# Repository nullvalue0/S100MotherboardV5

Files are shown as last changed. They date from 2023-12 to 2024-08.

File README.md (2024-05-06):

# S-100 Motherboard V5
## 9-Slot Active Termination S-100 Motherboard with Integrated Power Supply

This motherboard is an update to the publically available motherboard designs at http://www.s100computers.com/My%20System%20Pages/S100%20Motherboard/S100%20Motherboard.htm.

I really enjoy working on vintage S-100 systems, however they are very heavy/bulky systems and do not lend themselves well to testing small systems or performing bench diagnostics. I would really like to have a small motherboard that has all of the power requirements already taken care of. The previous motherboard design relies on an external power supply to provide the "odd" voltages (by today's standards): +8V, +16V and -16V. Generating these voltages usually means cobbling together a few Meanwell (or similar) power supplies. This version uses 3 different switched mode power regulator modules to get "close enough" to the S-100 voltages. I've gone with a 7.5V and 15V module from Pololu, and a negative module providing -15V made by TI. Each S-100 card has their own voltage regulator(s) which convert the motherboard voltages to +5V, often times ±12V. Due to this, being off 0.5-1V in our motherboard shouldn't cause any issues. In fact the slightly lower voltages should help the boards run slightly cooler. The motherboard receives base power from an external 24V laptop power supply, through a barrel jack connector.

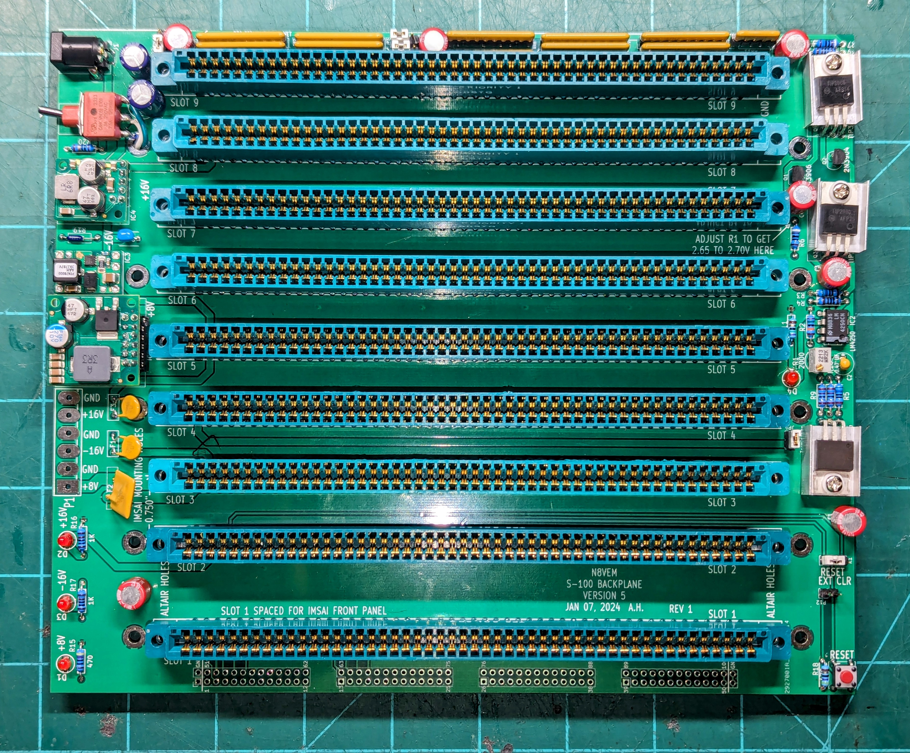
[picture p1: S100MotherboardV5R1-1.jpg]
S-100 Motherboard V5


One limitation of using these switching regulators is that current will be limited. It should be ok to power 3 or 4 standard S-100 cards. Any more than that and you'll start to push the limits. This motherboard is not intended to run large/power-hungry systems. Please be considerate of the amperage requirements of the cards you are using. I'd suggest using SIP socket strips for mounting the power supplies. That way if you need to provide external power for one of the voltages, say the +8V line, you could easily remove the 7.5V module and provide power from a bench supply.

If you do choose to populate the active termination components (which is optional, BTW) then I'd also recommend using SIP socket strips to populate the resistor packs. This way if you have a board set you want to use without termination, you can easily disable this feature by removing the resistors and the JP4 jumper.

I have a project set up through Mouser which has most of the parts required to build this motherboard: https://www.mouser.com/ProjectManager/ProjectDetail.aspx?AccessID=847fe5a657

There are a few parts not included in the Mouser project above:
- LM4250CN - this Op Amp IC is discontinued but can still be found on eBay
- 24V power supply (5.5mm x 2.1mm barrel connector). While I targeted a 24V input, any voltage between 15V-29V should work. I ordered the 7A version of this one and it's working great: https://www.ebay.com/itm/393979601717?var=662535600213
- 7.5V, 5A Step-Down Voltage Regulator D36V50F7 https://www.pololu.com/product/4093
- 15V, 2.7A Step-Down Voltage Regulator D30V30F15 https://www.pololu.com/product/4897
- S-100 slot connectors - sorry you're on your own for these - they can be expensive ($12-17 ea), so populate as few or as many as you'll actually need.
- 3 standard LEDs (I had plenty in my parts bin)
- Jumpers (will need up to 8)
- 2.54mm pitch pin headers for jumpers
- 3 heatsinks for TO-220 parts (7805 and TIP29/30)

This revision has kept all the great features of the V3 and V4 motherboards including:
- Active Termination to accomodate fasters speeds on the bus
- 9 S-100 slots
- Expansion/Logic Analyzer hookups
- Fused external power supply connector
- Mounting holes for Altair/IMSAI cases
- Reset switch

And I've done the following:
- Updated schematic/pcb to Kicad 7.0 and included all necessary libraries
- Synced up all parts between schematic & PCB to allow execution of DRC
- Increased edge connector pin hole sizes to 0.042"
- Changed fuses to resettable fuses
- Added 3 On-board power supplies
- Added Power On/Off toggle switch
- Added 3-way jumpers for 3 legacy pins to choose if you want to ground those pins, leave them unterminated, or active terminated
- Added jumper to enable/disable active termination power and indicator LED

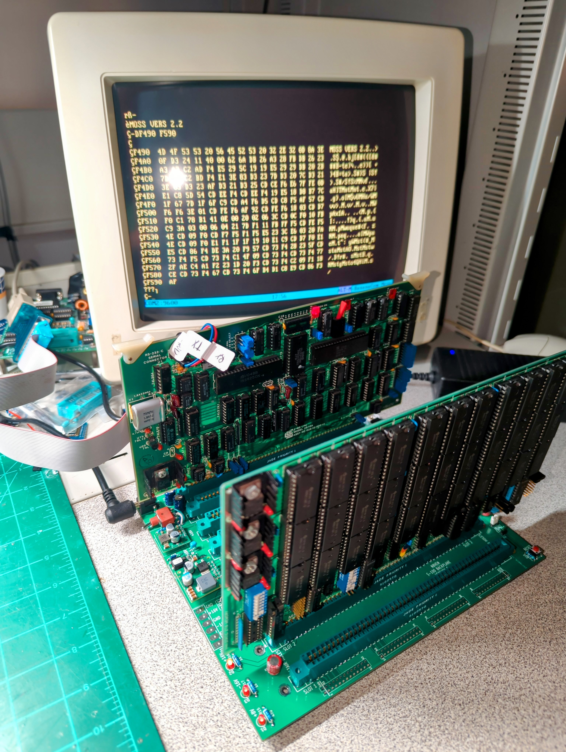
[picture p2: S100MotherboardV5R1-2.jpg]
S-100 Motherboard V5 In Use


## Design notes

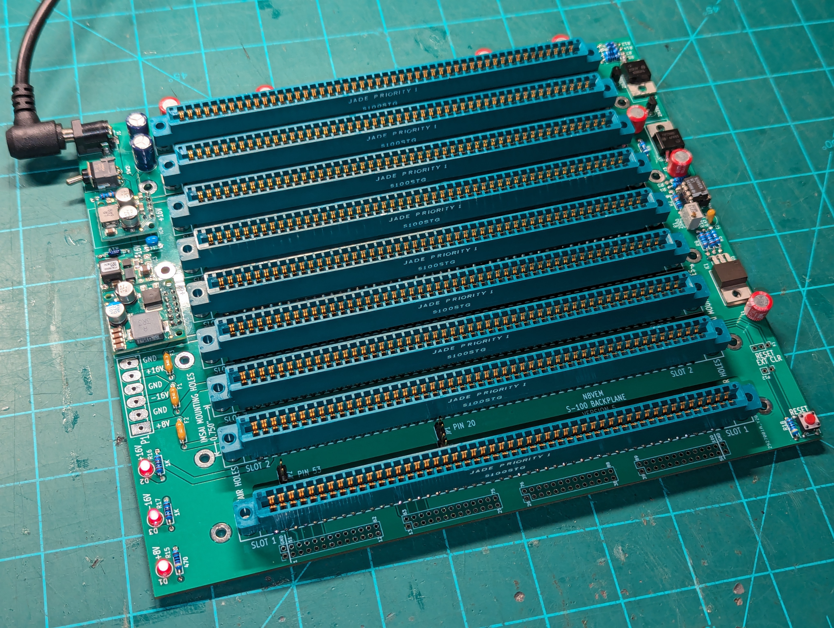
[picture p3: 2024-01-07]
S100MotherboardV5.jpg

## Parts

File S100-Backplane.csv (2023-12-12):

Source: | C:\Projects\S100 Backplane\S100 Backplane V5\S100-Backplane.kicad_sch
Date: | 12/10/2023 2:34:20 PM
Tool: | Eeschema 7.0.5
Generator: | C:\Program Files\KiCad\7.0\bin\scripting\plugins/bom_csv_grouped_by_value.py
Component Count: | 83
Collated Components:
Item | Qty | Reference(s) | Value | LibPart | Footprint | Datasheet | DNP | Description | Field4 | Field8 | Height | Manufacturer_Name | Manufacturer_Part_Number | Mouser Part Number | Mouser Price/Stock
1 | 7 | C1, C3, C4, C5, C6, C7, C8 | 39 UF | S100-Backplane-rescue:CP | C1V7
2 | 1 | C2 | 0.47 UF | S100-Backplane-rescue:CP | C1V7
3 | 2 | C9, C11 | 100uF 50V | SamacSys_Parts:ELXZ500ELL101MH12D | samac:CAPPRD350W60D825H1350 | https://componentsearchengine.com/Datasheets/2/ELXZ500ELL101MH12D.pdf |  |  |  |  | 13.5 | Chemi-Con | ELXZ500ELL101MH12D | 661-ELXZ500ELL101MH1 | https://www.mouser.co.uk/ProductDetail/Chemi-Con/ELXZ500ELL101MH12D?qs=Bh08734uQZCPydub3Junyw%3D%3D
4 | 1 | C10 | 4.7uF 50V | SamacSym:RCER71H475K3M1H03A | RDER72E154K3M1H03A | https://psearch.en.murata.com/capacitor/product/RCER71H475K3M1H03A.html |  |  |  |  | 6.5 | Murata Electronics | RCER71H475K3M1H03A | 81-RCER71H475K3M1H3A | https://www.mouser.co.uk/ProductDetail/Murata-Electronics/RCER71H475K3M1H03A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
5 | 3 | D1, D2, D3 | LED | S100-Backplane-rescue:LED | LEDV
6 | 3 | F1, F2, F3 | FUSE | S100-Backplane-rescue:FUSE | R5
7 | 1 | IC1 | 7805 | S100-Backplane-rescue:7805 | LM78XX
8 | 1 | IC2 | LM4250 | :LM4250_2 | 8dip300 |  |  | ORDER FROM EBAY | 386 | 386
9 | 1 | IC3 | PTN78000AAH | SamacSys_Parts:PTN78000AAH | samac:EUS_R-PDSS-T5_ | http://www.ti.com/lit/ds/symlink/ptn78000a.pdf |  |  |  |  |  | Texas Instruments | PTN78000AAH | 595-PTN78000AAH | https://www.mouser.co.uk/ProductDetail/Texas-Instruments/PTN78000AAH?qs=sSOk4GDDv7xMxL4enD0otw%3D%3D
10 | 1 | IC4 | 15V D30V30F15 | Connector_Generic:Conn_01x05 | S100 Backplane:D30V30F15 | ~ |  | ORDER FROM POLOLU
11 | 1 | IC5 | 7.5V D36V50F7 | Connector_Generic:Conn_02x06_Odd_Even | S100 Backplane:D36V50F7 | ~ |  | ORDER FROM POLOLU
12 | 1 | J1 | Barrel_Jack_MountingPin | Connector:Barrel_Jack_MountingPin | Connector_BarrelJack:BarrelJack_Horizontal | ~
13 | 3 | JP1, JP2, JP3 | JUMPER | S100-Backplane-rescue:JUMPER | SIL-2
14 | 1 | K1 | CONN_3 | S100-Backplane-rescue:CONN_3 | Connector_PinHeader_2.54mm:PinHeader_1x03_P2.54mm_Vertical
15 | 1 | P1 | CONN_3X2 | S100-Backplane-rescue:CONN_3X2 | bornier6
16 | 4 | P2, P3, P4, P5 | CONN_13X2 | S100-Backplane-rescue:CONN_13X2 | Connector_PinHeader_2.54mm:PinHeader_2x13_P2.54mm_Vertical
17 | 6 | P6, P7, P8, P9, P10, P11 | CONN_1 | S100-Backplane-rescue:CONN_1 | 1pin
18 | 1 | P12 | CONN_2 | S100-Backplane-rescue:CONN_2 | Connector_PinHeader_2.54mm:PinHeader_1x02_P2.54mm_Vertical
19 | 1 | Q1 | 2N3906TF | SamacSym:2N3906TF | TO_SOT_THT:TO-92 | https://www.onsemi.com/pub/Collateral/2N3906-D.pdf |  |  |  |  |  | onsemi | 2N3906TF | 512-2N3906TF | https://www.mouser.co.uk/ProductDetail/onsemi-Fairchild/2N3906TF?qs=2V4k6Hs0nQlRuTN1j8DMpA%3D%3D
20 | 1 | Q2 | 2N3904TA | SamacLib:2N3904TA | TO_SOT_THT:TO-92 | http://www.onsemi.com/pub/Collateral/2N3904-D.pdf |  | Transistor GP BJT NPN 40V 0.2A TO92-3 |  |  |  | onsemi | 2N3904TA | 512-2N3904TA | https://www.mouser.co.uk/ProductDetail/onsemi-Fairchild/2N3904TA?qs=ljbEvF4DwOOn1Ev%2FzRYaoA%3D%3D
21 | 1 | Q3 | TIP29BG | SamacLib:TIP29BG | TO_SOT_THT:TO-220-3_Horizontal_TabDown | https://ms.componentsearchengine.com/Datasheets/2/TIP29BG.pdf |  | ONSEMI - TIP29BG - Bipolar (BJT) Single Transistor, NPN, 80 V, 1 A, 30 W, TO-220, Through Hole |  |  | 4.7 | onsemi | TIP29BG
22 | 1 | Q4 | TIP30CG | SamacLib:TIP30CG | TO_SOT_THT:TO-220-3_Horizontal_TabDown | http://www.onsemi.com/pub/Collateral/TIP29B-D.PDF |  | Complementary Silicon Plastic Power Transistors |  |  | 4.83 | onsemi | TIP30CG | 863-TIP30CG | https://www.mouser.co.uk/ProductDetail/onsemi/TIP30CG?qs=xZq1yRCsb1fdZ1wKETGXLw%3D%3D
23 | 1 | R1 | 2000 | S100-Backplane-rescue:POT | RV2
24 | 1 | R2 | 150K | S100-Backplane-rescue:R | R3
25 | 2 | R3, R5 | 560 | S100-Backplane-rescue:R | R3
26 | 2 | R4, R8 | 1000 | S100-Backplane-rescue:R | R3
27 | 2 | R6, R7 | 910 | S100-Backplane-rescue:R | R3
28 | 2 | R9, R10 | 1800 | S100-Backplane-rescue:R | R3
29 | 4 | R11, R12, R13, R14 | 270 | S100-Backplane-rescue:R | R3
30 | 2 | R15, R18 | 470 | S100-Backplane-rescue:R | R3
31 | 2 | R16, R17 | 1K | S100-Backplane-rescue:R | R3
32 | 1 | R19 | 100R | Device:R | Resistor_THT:R_Axial_DIN0207_L6.3mm_D2.5mm_P10.16mm_Horizontal | ~
33 | 10 | RR1, RR2, RR3, RR4, RR5, RR6, RR7, RR8, RR9, RR10 | 270 | S100-Backplane-rescue:RR9 | Connector_PinHeader_2.54mm:PinHeader_1x10_P2.54mm_Vertical
34 | 1 | SW1 | SW_PUSH | S100-Backplane-rescue:SW_PUSH | SW_PUSH_SMALL
35 | 1 | SW2 | CWSA11AAN1H | SamacSys_Parts:CWSA11AAN1H | samac:CWSA11AAN1H | http://www.nkkswitches.com/pdf/CWS-2.pdf |  |  |  |  | 14.8 | NKK Switches | CWSA11AAN1H | 633-CWSA11AAN1H | https://www.mouser.co.uk/ProductDetail/NKK-Switches/CWSA11AAN1H?qs=Q3Z28Xqk4Z%252BPrQDMlrRWsA%3D%3D
36 | 9 | U31, U32, U33, U34, U35, U36, U37, U38, U39 | S100_FEMALE | S100-Backplane-rescue:S100_FEMALE | S100_FEMALE

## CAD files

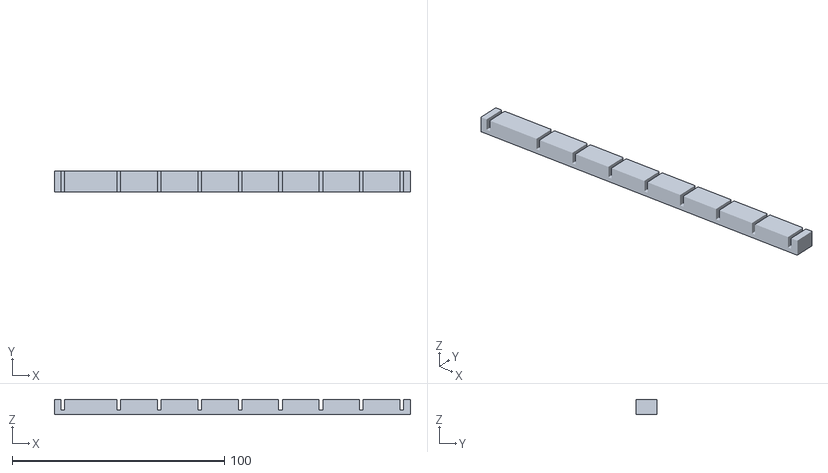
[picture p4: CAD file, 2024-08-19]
Card Stabilizers/Card Stabilizers.stl
167.7 x 10.0 x 7.00

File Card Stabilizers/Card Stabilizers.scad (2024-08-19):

slotWidth = 1.7;
length = 10;
offset = 3;
height = 7;
firstWidth = 26.41854;
remainingWidths = 19.05;

difference() {
    cube([167.7,10,height]);
        
    translate([offset, 0, 2]) {
        cube([slotWidth, length, height]);
    }

    translate([offset + firstWidth , 0, 2]) {
        cube([slotWidth, length, height]);
    }

    translate([offset + firstWidth + (remainingWidths*1), 0, 2]) {
        cube([slotWidth, length, height]);
    }
    translate([offset + firstWidth + (remainingWidths*2), 0, 2]) {
        cube([slotWidth, length, height]);
    }
    translate([offset + firstWidth + (remainingWidths*3), 0, 2]) {
        cube([slotWidth, length, height]);
    }
    translate([offset + firstWidth + (remainingWidths*4), 0, 2]) {
        cube([slotWidth, length, height]);
    }
    translate([offset + firstWidth + (remainingWidths*5), 0, 2]) {
        cube([slotWidth, length, height]);
    }
    translate([offset + firstWidth + (remainingWidths*6), 0, 2]) {
        cube([slotWidth, length, height]);
    }
    translate([offset + firstWidth + (remainingWidths*7), 0, 2]) {
        cube([slotWidth, length, height]);
    }


}

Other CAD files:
PTN78000AAH/Allegro/eus_r-pdss-t5_.psm
PTN78000AAH/DEHDL/ptn78000aah/chips/chips.prt

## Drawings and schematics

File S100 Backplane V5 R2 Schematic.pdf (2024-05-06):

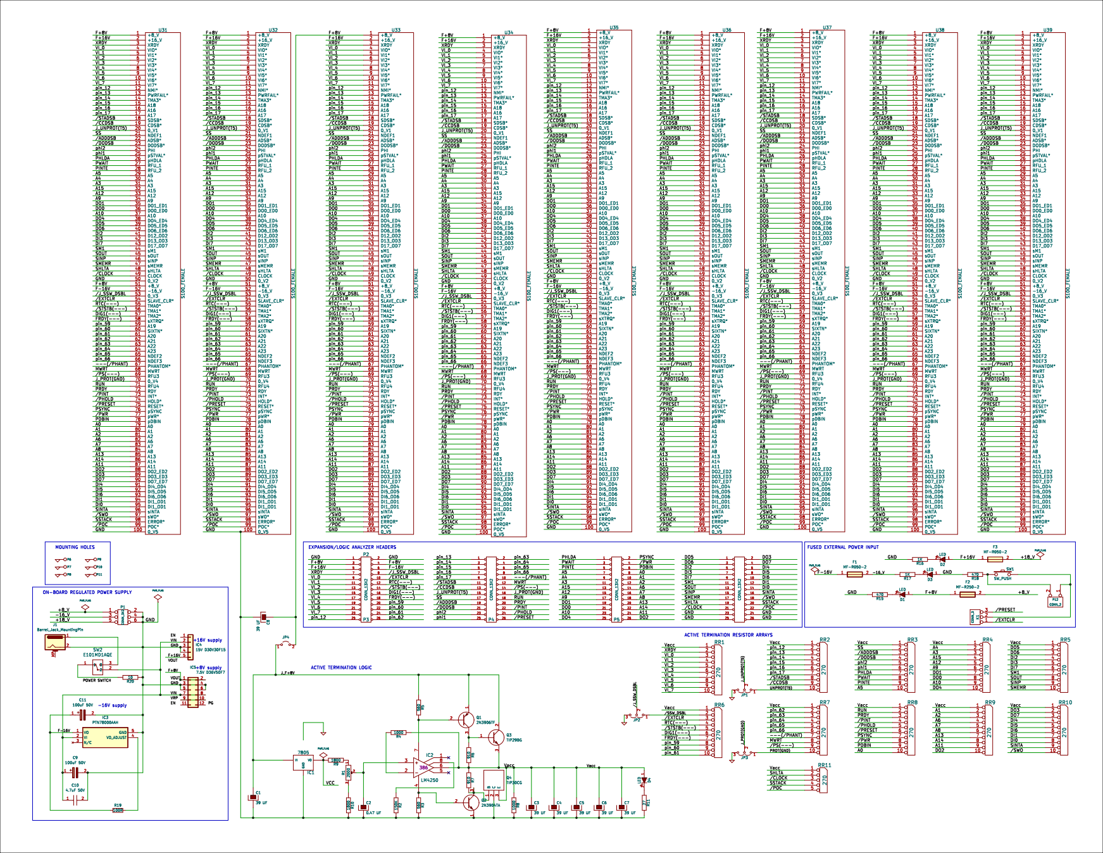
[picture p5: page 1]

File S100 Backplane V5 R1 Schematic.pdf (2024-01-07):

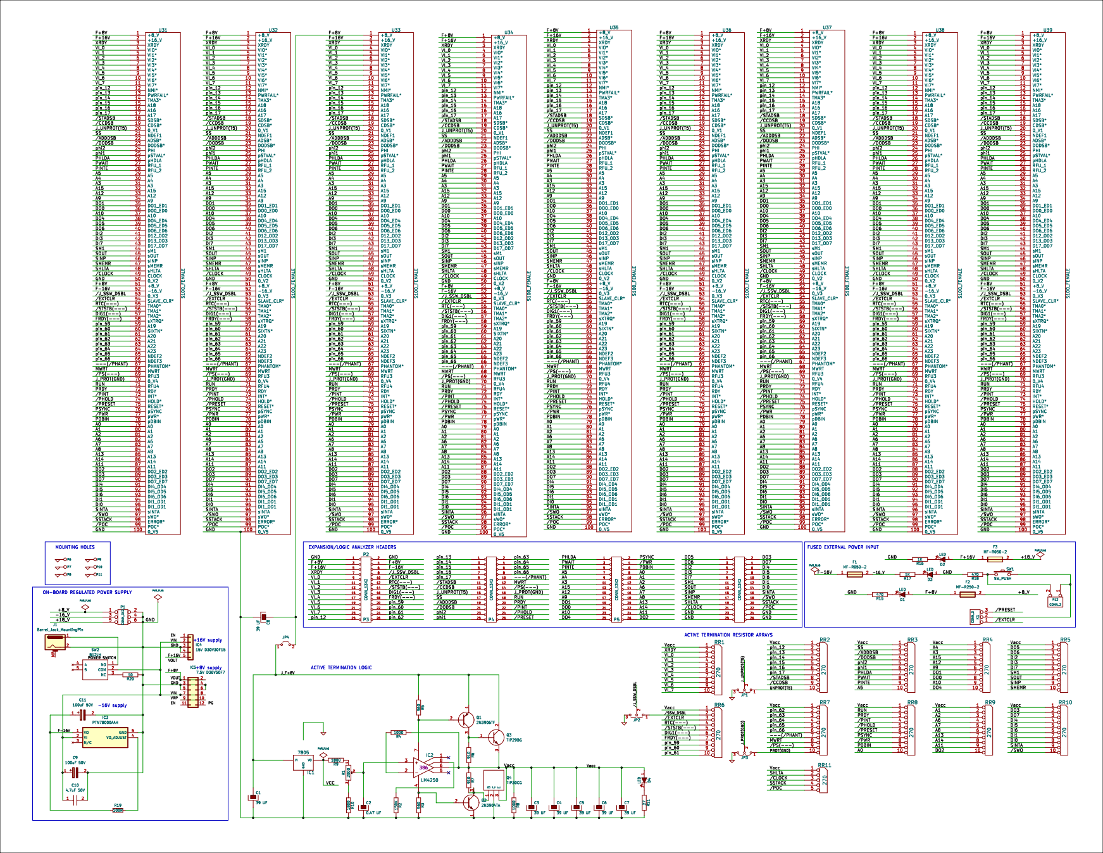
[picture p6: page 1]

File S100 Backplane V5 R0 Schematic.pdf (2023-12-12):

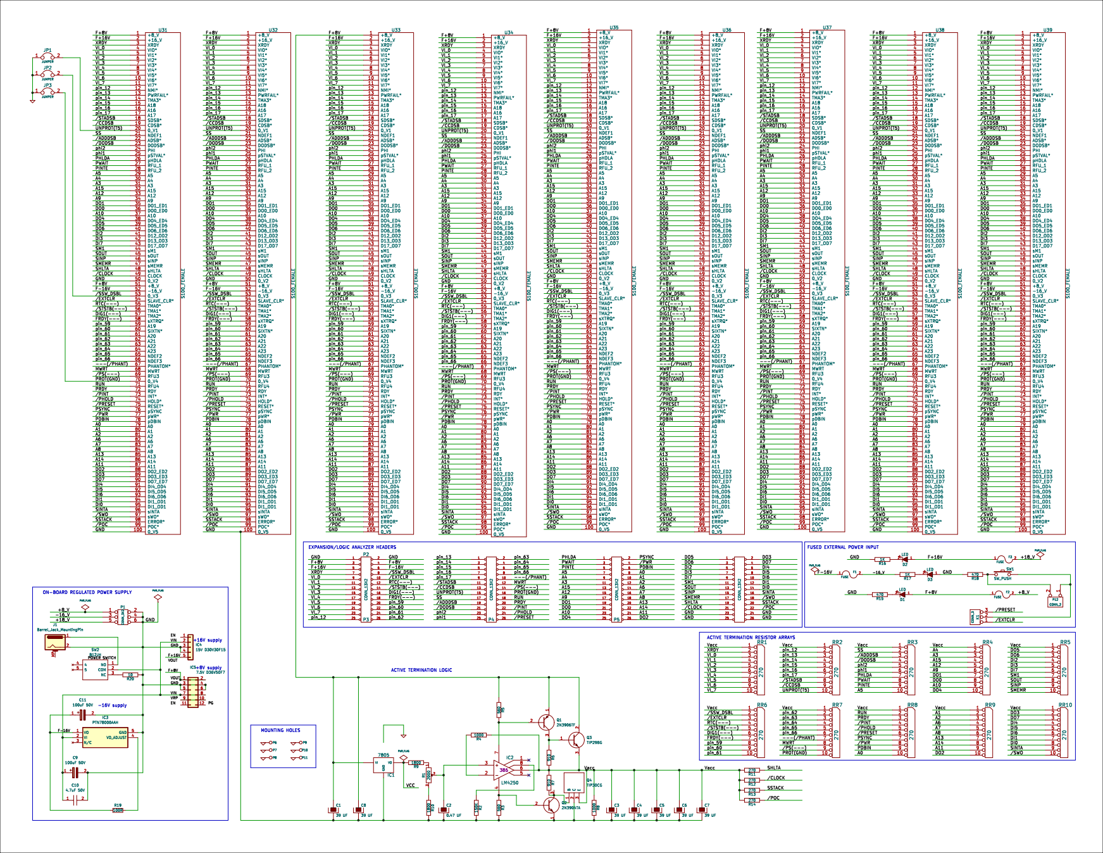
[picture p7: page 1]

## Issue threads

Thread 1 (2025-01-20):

V5 motherboard can't be connected to external power once the Pololu and T.I. ICs have been installed

smastrianni, 2025-01-20:
Once the Pololu and T.I. ICs have been installed, the motherboard can no longer be connected to external power via the P1 connector on the motherboard. Doing so causes the external power to back feed into the  T.I. and Pololu ICs, immediately destroying the -15V T.I. module.

If more power is required, the user should be able to use an external power supply instead of the onboard power supply. At a minimum, the power modules should be protected, perhaps with diodes, and maybe an additional switch to select the power source.

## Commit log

2023-12-13 Updated gerbers
    [S100-Backplane-B_Mask.gbs, S100-Backplane-Component.gtl, S100-Backplane-Copper.gbl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]
2024-01-07 Rev 1
    [S100-Backplane-B_Mask.gbs, S100-Backplane-B_Silkscreen.gbo, S100-Backplane-Component.gtl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]
2024-05-06 R2
    Updated SW2 power switch footprint to beefier part, E101MD1AQE.
    [S100-Backplane-2023-11-26-14-36-15.sch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]
2024-08-19 Added 3D-printed Card Stabilizers
    Created these 3d-printed card stabilizer/spacer which helps create a lot of stability for the cards in a free-standing motherboard like this. Not as good as a full card cage, but a lot better than nothing.
    [Card Stabilizers.scad, Card Stabilizers.stl]
